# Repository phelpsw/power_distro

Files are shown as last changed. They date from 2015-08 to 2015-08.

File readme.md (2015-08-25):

## Dependencies

### Libs
 * https://github.com/phelpsw/kicad-libs
 * http://smisioto.no-ip.org/kicad_libs/library/lib_w_connectors.zip
 * http://smisioto.no-ip.org/kicad_libs/library/lib_w_transistor.zip
 * http://smisioto.no-ip.org/kicad_libs/library/lib_w_analog.zip

### Footprints
 * http://smisioto.no-ip.org/kicad_libs/modules/mod_conn_rf.zip
 * http://smisioto.no-ip.org/kicad_libs/modules/mod_smd_cap.zip
 * http://smisioto.no-ip.org/kicad_libs/modules/mod_smd_dil.zip
 * http://smisioto.no-ip.org/kicad_libs/modules/mod_smd_diode.zip
 * http://smisioto.no-ip.org/kicad_libs/modules/mod_smd_inductors.zip
 * http://smisioto.no-ip.org/kicad_libs/modules/mod_smd_leds.zip
 * http://smisioto.no-ip.org/kicad_libs/modules/mod_smd_resistors.zip
 * http://smisioto.no-ip.org/kicad_libs/modules/mod_smd_trans.zip
 * http://smisioto.no-ip.org/kicad_libs/modules/mod_conn_jst-ph.zip

### Models
 * http://smisioto.no-ip.org/kicad_libs/packages3d/3d_conn_df13.zip
 * http://smisioto.no-ip.org/kicad_libs/packages3d/3d_conn_rf.zip
 * http://smisioto.no-ip.org/kicad_libs/packages3d/3d_smd_cap.zip
 * http://smisioto.no-ip.org/kicad_libs/packages3d/3d_smd_dil.zip
 * http://smisioto.no-ip.org/kicad_libs/packages3d/3d_smd_diode.zip
 * http://smisioto.no-ip.org/kicad_libs/packages3d/3d_smd_inductors.zip
 * http://smisioto.no-ip.org/kicad_libs/packages3d/3d_smd_leds.zip
 * http://smisioto.no-ip.org/kicad_libs/packages3d/3d_smd_resistors.zip
 * http://smisioto.no-ip.org/kicad_libs/packages3d/3d_smd_trans.zip
 * http://smisioto.no-ip.org/kicad_libs/packages3d/3d_conn_jst-ph.zip

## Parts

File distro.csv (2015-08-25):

ref | value | Field1
BT1 | BATTERY | P223-ND
C1 | 100uF | 493-2226-2-ND
C2 | 100uF | 493-2226-2-ND
C3 | DNP
C4 | 10uF | 399-11082-1-ND
C5 | 0.1uF | 399-11163-1-ND
C6 | 0.033uF | 478-3769-1-ND
C7 | 0.033uF | 478-3769-1-ND
C8 | 0.033uF | 478-3769-1-ND
C9 | 0.1uF | 399-11163-1-ND
C10 | 0.1uF | 399-11163-1-ND
C11 | 0.1uF | 399-11163-1-ND
C12 | 0.022uF | 490-8308-1-ND
C13 | 0.022uF | 490-8308-1-ND
C14 | 0.022uF | 490-8308-1-ND
C15 | 0.022uF | 490-8308-1-ND
C16 | 0.022uF | 490-8308-1-ND
C17 | 0.022uF | 490-8308-1-ND
C18 | 0.1uF | 399-11163-1-ND
C19 | 0.1uF | 399-11163-1-ND
C20 | 0.1uF | 399-11163-1-ND
C21 | 0.1uF | 399-11163-1-ND
C22 | 0.1uF | 399-11163-1-ND
C23 | 0.1uF | 399-11163-1-ND
C24 | 0.1uF | 399-11163-1-ND
C25 | 0.1uF | 399-11163-1-ND
C26 | 0.1uF | 399-11163-1-ND
C27 | 0.1uF | 399-11163-1-ND
C28 | 10uF | 399-11082-1-ND
C29 | 100uF | 493-2226-2-ND
C30 | 1uF | 399-8147-1-ND
C31 | 1uF | 399-8147-1-ND
C32 | 10uF | 399-11082-1-ND
C33 | 1uF | 399-8147-1-ND
C34 | 0.1uF | 399-11163-1-ND
C35 | 0.1uF | 399-11163-1-ND
C36 | 0.022uF | 490-8308-1-ND
C37 | 1uF | 399-8147-1-ND
C38 | 0.1uF | 399-11163-1-ND
C39 | 47pF | 399-9083-1-ND
D1 | LED Green | 160-1218-1-ND
D2 | LED Green | 160-1218-1-ND
D3 | MB3045S-E3/8W | MB3045S-E3/8WGICT-ND
D4 | BI_LED | VLMV3100-GS08CT-ND
D5 | BI_LED | VLMV3100-GS08CT-ND
D6 | BI_LED | VLMV3100-GS08CT-ND
D7 | BI_LED | VLMV3100-GS08CT-ND
D8 | BI_LED | VLMV3100-GS08CT-ND
D9 | BI_LED | VLMV3100-GS08CT-ND
D10 | LED Green | 160-1218-1-ND
D11 | BI_LED | VLMV3100-GS08CT-ND
F1 | 4A 5V | F5786CT-ND
F2 | 4A 5V | F5786CT-ND
F3 | 4A 5V | F5786CT-ND
F4 | 4A 5V | F5786CT-ND
F5 | 4A 5V | F5786CT-ND
F6 | 4A 5V | F5786CT-ND
F7 | 4A 5V | F5786CT-ND
F8 | 4A 5V | F5786CT-ND
F9 | 1.85A 24V | F2871CT-ND
F10 | 1.1A 5V | F3366CT-ND
F11 | 1.1A 24V | F2868CT-ND
F12 | 2.6A 5V | F4242CT-ND
F13 | 1.1A 24V | F2868CT-ND
F14 | 1.1A 5V | F3366CT-ND
F15 | 1.1A 5V | F3366CT-ND
F16 | 1.85A 24V | F2871CT-ND
F17 | 1.1A 5V | F3366CT-ND
F18 | 1.6A 24V | F2870CT-ND
F19 | 1.6A 24V | F2870CT-ND
F20 | 1.1A 24V | F2868CT-ND
F21 | 1.6A 24V | F2870CT-ND
F22 | 1.1A 24V | F2868CT-ND
F23 | 1.6A 24V | F2870CT-ND
F24 | 1.1A 24V | F2868CT-ND
F25 | 1.1A 24V | F2868CT-ND
F26 | 1.1A 24V | F2868CT-ND
F27 | 1.1A 24V | F2868CT-ND
F28 | 1.1A 5V | F3366CT-ND
F29 | 1.1A 5V | F3366CT-ND
F30 | 1.5A 5V | F3367CT-ND
F31 | 1.1A 24V | F2868CT-ND
F32 | 1.1A 24V | F2868CT-ND
F33 | 1.85A 24V | F2871CT-ND
J1 | MEGAFIT-4SKT | WM10392-ND
J2 | DF13-4 | H3434-ND
J3 | DF13-6 | H3436-ND
J4 | DF13-5 | H3435-ND
J5 | DF13-6 | H3436-ND
J6 | SSW-116-02-S-TRA
J7 | TSW-106-02-S-TRA
J8 | SSW-108-02-S-D-RA
J9 | SSW-106-02-G-D-RA
J10 | JST-PA-4 | 455-2645-1-ND
J11 | JST-PA-2 | 455-2650-1-ND
J12 | JST-PA-2 | 455-2650-1-ND
J13 | DF13-4 | H3434-ND
J14 | JST-PA-2 | 455-2650-1-ND
J15 | JST-PA-2 | 455-2650-1-ND
J16 | JST-PA-2 | 455-2650-1-ND
J17 | JST-PA-3 | 455-2644-1-ND
J18 | JST-PA-3 | 455-2644-1-ND
J19 | JST-PA-4 | 455-2645-1-ND
J20 | JST-PA-4 | 455-2645-1-ND
J21 | JST-PA-3 | 455-2644-1-ND
J22 | JST-PA-3 | 455-2644-1-ND
J23 | JST-PA-2 | 455-2650-1-ND
J24 | JST-PA-2 | 455-2650-1-ND
J25 | JST-PA-2 | 455-2650-1-ND
J26 | JST-PA-2 | 455-2650-1-ND
J27 | DF13-6 | H3436-ND
L1 | 27nH | 490-2628-1-ND
P1 | Pad
P2 | SMA RA | A97593-ND
Q1 | IRFZ44 | IRFZ44STRRPBFCT-ND
Q2 | IRFZ44 | IRFZ44STRRPBFCT-ND
Q3 | IRFZ44 | IRFZ44STRRPBFCT-ND
Q4 | IRFZ44 | IRFZ44STRRPBFCT-ND
Q5 | IRFZ44 | IRFZ44STRRPBFCT-ND
Q6 | IRFZ44 | IRFZ44STRRPBFCT-ND
Q7 | IRFZ44 | IRFZ44STRRPBFCT-ND
Q8 | IRFZ44 | IRFZ44STRRPBFCT-ND
R1 | DNP
R2 | DNP
R3 | DNP
R4 | DNP
R5 | 2m | LVK25R002DERCT-ND
R6 | 68.1k | P68.1KDACT-ND
R7 | 10k | P10KBFCT-ND
R8 | 1.3k | P1.3KBFCT-ND
R9 | 2m | LVK25R002DERCT-ND
R10 | 75k | P75KDACT-ND
R11 | 10m | LVK25R010DERCT-ND
R12 | 100k | P100KCCT-ND
R13 | 150 | P150DACT-ND
R14 | 4.42k | P4.42KCCT-ND
R15 | 470 | P470CCT-ND
R16 | 100k | P100KCCT-ND
R17 | 510 | P510FCT-ND
R18 | 100k | P100KCCT-ND
R19 | 57.6k | P57.6KDACT-ND
R20 | 300 | P300CCT-ND
R21 | 47.5k | P47.5KDACT-ND
R22 | 66.5k | P66.5KDACT-ND
R23 | 300 | P300CCT-ND
R24 | 300 | P300CCT-ND
R25 | 47.5k | P47.5KDACT-ND
R26 | 66.5k | P66.5KDACT-ND
R27 | 300 | P300CCT-ND
R28 | 300 | P300CCT-ND
R29 | 57.6k | P57.6KDACT-ND
R30 | 57.6k | P57.6KDACT-ND
R31 | 300 | P300CCT-ND
R32 | 300 | P300CCT-ND
R33 | 4.42k | P4.42KCCT-ND
R34 | 4.42k | P4.42KCCT-ND
R35 | 4.42k | P4.42KCCT-ND
R36 | 1M | P1.00MCCT-ND
R37 | FILTER | 490-4003-1-ND
R38 | FILTER | 490-4003-1-ND
R39 | 10 | RNCP0805FTD10R0CT-ND
SW1 | M2022LL2W13 | 360-3095-ND
U1 | VHE100W | 102-2639-ND
U2 | VQE50W | 102-2627-ND
U3 | 74LS74 | 296-1079-1-ND
U4 | INA139 | 296-26061-1-ND
U5 | INA139 | 296-26061-1-ND
U6 | INA139 | 296-26061-1-ND
U7 | 74LS74 | 296-1079-1-ND
U8 | MIC5014 | 576-1233-1-ND
U9 | MIC5014 | 576-1233-1-ND
U10 | 74LS74 | 296-1079-1-ND
U11 | 74LS74 | 296-1079-1-ND
U12 | MIC5014 | 576-1233-1-ND
U13 | MIC5014 | 576-1233-1-ND
U14 | 74LS74 | 296-1079-1-ND
U15 | 74LS74 | 296-1079-1-ND
U16 | MCP601-SOT | MCP601T-I/OTCT-ND
U17 | MCP601-SOT | MCP601T-I/OTCT-ND
U18 | MCP601-SOT | MCP601T-I/OTCT-ND
U19 | MCP601-SOT | MCP601T-I/OTCT-ND
U20 | PQD6-D | 102-2886-ND
U21 | MS4525DO-DS | 223-1110-ND
U22 | 74LS74 | 296-1079-1-ND
U23 | TC1055 | TC10553.3VCT713CT-ND
U24 | NEO-M8

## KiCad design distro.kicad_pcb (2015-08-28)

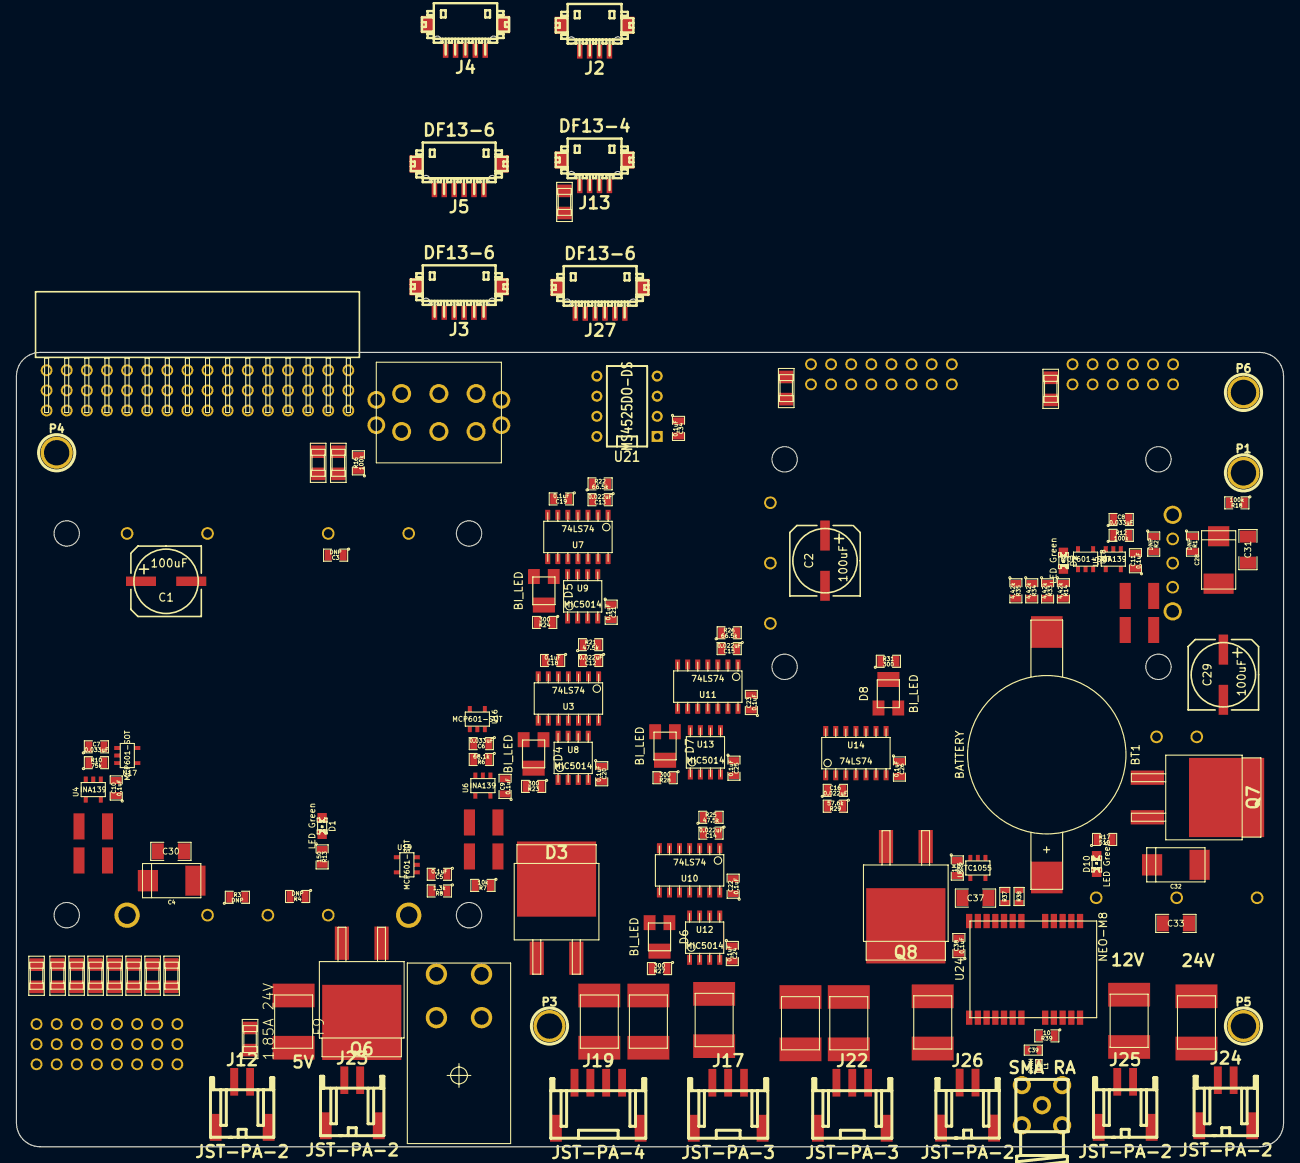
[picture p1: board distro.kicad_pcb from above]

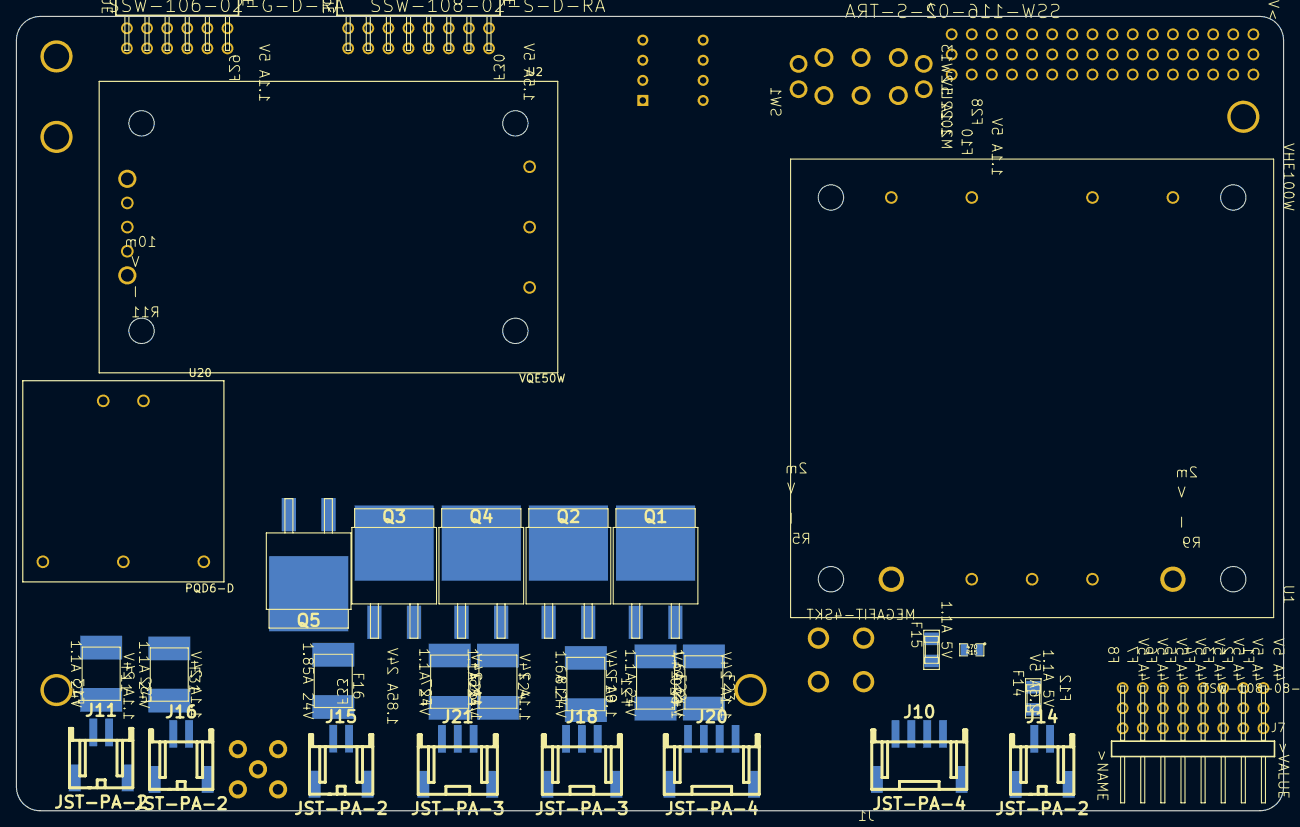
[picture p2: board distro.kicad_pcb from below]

Board: 2 copper layers, 160.0 x 100.3 mm, 178 parts (30 on the bottom side), 130 nets, no tracks yet.

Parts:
BT1: BATTERY; BR2032
C1, C2, C29: 100uF; SMDHD/VF
C3: DNP; SM0805
C4, C28, C32: 10uF; c_tant_V
C5, C9, C10, C11, C18, C19, C20, C21, C22, C23, C24, C25, C26, C34, C38: 0.1uF; SM0805
C6, C7, C8: 0.033uF; SM0805
C12, C13, C14, C15, C16: 0.022uF; SM0805
C30, C31, C33, C37: 1uF; SM1206
C39: 47pF; SM0603
D1, D2, D10: LED Green; LED-0805
D3: MB3045S-E3/8W; d2-pak
D4, D5, D6, D7, D8: BI_LED; LED_PLCC3
F1, F2, F3, F4, F5, F6, F7, F8: 4A 5V; littelfuse-1206
F9, F16, F33: 1.85A 24V; littelfuse-2920L
F10, F14, F15, F17, F28, F29: 1.1A 5V; littelfuse-1206
F11, F13, F20, F22, F24, F25, F26, F27, F31, F32: 1.1A 24V; littelfuse-2920L
F12: 2.6A 5V; littelfuse-1206
F18, F19, F21, F23: 1.6A 24V; littelfuse-2920L
F30: 1.5A 5V; littelfuse-1206
J1: MEGAFIT-4SKT; molex-MEGAFIT-4SKT-RA
J2, J13: DF13-4; df13-4p-125h
J3, J5, J27: DF13-6; df13-6p-125h
J4: DF13-5; df13-5p-125h
J6: SSW-116-02-S-TRA; con-samtec-SSW-116-02-S-T-RA
J7: TSW-108-08-G-T-RA; con-samtec-TSW-108-02-S-T-RA
J8: SSW-108-02-S-D-RA; con-samtec-SSW-108-02-S-D-RA
J9: SSW-106-02-G-D-RA; con-samtec-SSW-106-02-S-D-RA
J10, J19, J20: JST-PA-4; s4b-ph-sm4-tb
J11, J12, J14, J15, J16, J23, J24, J25, J26: JST-PA-2; s2b-ph-sm4-tb
J17, J18, J21, J22: JST-PA-3; s3b-ph-sm4-tb
L1: 27nH; inductor_smd_0402
P1, P3, P4, P5, P6: Pad; 1pin
P2: SMA RA; sma_90_r300.124.403
Q1, Q2, Q3, Q4, Q5, Q6, Q7, Q8: IRFZ44; d2-pak
R1, R2, R3, R4: DNP; SM0805
R5, R9: 2m; LVK25
R6: 68.1k; SM0805
R7: 10k; SM0805
R8: 1.3k; SM0805
R10: 75k; SM0805
R11: 10m; LVK25
R12, R16, R18: 100k; SM0805
R13: 150; SM0805
R14, R33, R34, R35: 4.42k; SM0805
R15: 470; SM0805
R17: 510; SM0805
R21, R25: 47.5k; SM0805
R22, R26: 66.5k; SM0805
R23, R24, R27, R28, R31: 300; SM0805
R29: 57.6k; SM0805
R36: 1M; SM0805
R37, R38: FILTER; SM0603
R39: 10; SM0805
SW1: M2022LL2W13; switch-M2022LL2W13
U1: VHE100W
U2: VQE50W
U3, U7, U10, U11, U14: 74LS74; so-14
U4, U5, U6: INA139; SOT23-5
U8, U9, U12, U13: MIC5014; so-8
U16, U17, U18, U19: MCP601-SOT; SOT23-5
U20: PQD6-D
U21: MS4525DO-DS; DIP-8__300
U23: TC1055; SOT23-5
U24: NEO-M8; NEO-M8N

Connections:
+3.3V: C37.1, C38.1, U23.5, U24.23
+5V: C9.1, C10.1, C11.1, C18.1, C19.1, C20.1, C21.1, C22.1, C23.1, C24.1, C25.1, C26.1, C34.1, D1.1, F1.1, F2.1, F3.1, F4.1, F5.1, F6.1, F7.1, F8.1, F9.2, F10.2, F12.2, F14.2, F15.2, F17.2, F28.2, F29.2, F30.2, Q7.1, R9.1, R36.1, U3.2, U3.4, U3.10, U3.13, U3.14, U4.5, U5.5, U6.5, U7.2, U7.4, U7.10, U7.13, U7.14, U8.1, U9.1, U10.2, U10.4, U10.10, U10.13, U10.14, U11.2, U11.4, U11.10, U11.13, U11.14, U12.1, U13.1, U14.2, U14.4, U14.10, U14.13, U14.14, U16.5, U17.5, U18.5, U19.5, U21.2, U23.1
+12V: C32.1, C33.1, D10.1, F31.2, F32.2, F33.2, U20.3
+24V: D2.1, F11.2, F13.2, F16.2, R11.1
+BATT: C1.1, C2.1, C29.1, Q1.2, Q2.2, Q3.2, Q4.2, R5.1, U1.1, U2.1, U20.2
/Identification Lights/RC_IN: U3.3, U3.12, U7.3, U7.12
/Identification Lights/STROBE: F18.2, F19.2, F21.2, F23.2, Q2.3, U9.3
/Identification Lights/SYNC: J17.3, J18.3, J19.4, J20.4
/Identification Lights/WING_LIGHT: F20.2, F22.2, Q1.3, U8.3
/Landing Lights/LANDING: F24.2, F26.2, Q4.3, U13.3
/Landing Lights/RC_IN: U10.3, U10.12, U11.3, U11.12
/Landing Lights/TAXI: F25.2, F27.2, Q3.3, U12.3
/Lidar/AUX5 (Mode): J10.3, R15.1
/Payload/Payload_Switched: D8.1, Q5.1, Q6.1, Q8.1, U14.9
/Payload/RC_IN: U14.3, U14.12
/Pixhawk/5V_CURR_MEAS: J4.2, U17.1, U17.4
/Pixhawk/24V_CURR_MEAS: J4.4, U18.1, U18.4
/Pixhawk/FMAIN1_5V: F1.2, J7.2
/Pixhawk/FMAIN2_5V: F2.2, J7.5
/Pixhawk/FMAIN3_5V: F3.2, J7.8
/Pixhawk/FMAIN4_5V: F4.2, J7.11
/Pixhawk/FMAIN5_5V: F5.2, J7.14
/Pixhawk/FMAIN6_5V: F6.2, J7.17
/Pixhawk/FMAIN7_5V: F7.2, J7.20
/Pixhawk/FMAIN8_5V: F8.2, J7.23
/Pixhawk/MAIN1: J6.30, J7.3
/Pixhawk/MAIN2: J6.27, J7.6
/Pixhawk/MAIN3: J6.24, J7.9
/Pixhawk/MAIN4: J6.21, J7.12
/Pixhawk/MAIN5: J6.18, J7.15
/Pixhawk/MAIN6: J6.15, J7.18
/Pixhawk/MAIN7: J6.12, J7.21
/Pixhawk/MAIN8: J6.9, J7.24
/Pixhawk/MEAS_CURRENT: J3.3, U16.1, U16.4
/Pixhawk/MEAS_VOLTAGE: J3.4, U19.1, U19.4
/Pixhawk/RC_SIG: J6.3, J9.1
/Power/5V_ONOFF: SW1.P2, U1.2
/Power/24V_ONOFF: SW1.P5, U2.2
GND: BT1.2, C1.2, C2.2, C3.1, C4.2, C5.2, C6.2, C7.1, C8.1, C9.2, C10.2, C11.2, C12.2, C13.2, C14.2, C15.2, C16.2, C18.2, C19.2, C20.2, C21.2, C22.2, C23.2, C24.2, C25.2, C26.2, C28.2, C30.2, C31.2, C32.2, C33.2, C34.2, C37.2, C38.2, C39.2, J1.3, J1.4, J2.4, J3.5, J3.6, J4.3, J4.5, J5.6, J6.1, J6.4, J6.7, J6.10, J6.13, J6.16, J6.19, J6.22, J6.25, J6.28, J6.31, J6.34, J6.37, J6.40, J6.43, J6.46, J7.1, J7.4, J7.7, J7.10, J7.13, J7.16, J7.19, J7.22, J8.1, J9.5, J10.4, J11.2, J12.2, J13.4, J14.2, J16.2, J17.2, J18.2, J19.3, J20.3, J21.3, J22.3, J24.2, J25.2, J27.6, P2.2, Q5.3, Q6.3, Q7.3, Q8.3, R2.1, R4.1, R6.2, R8.2, R10.1, R12.1, R13.2, R14.2, R15.2, R16.2, R17.2, R18.2, R23.2, R24.2, R27.2, R28.2, R31.2, R33.2, R34.2, R35.2, SW1.P1, SW1.P4, U1.4, U1.5, U1.6, U2.3, U2.4, U2.5, U3.7, U4.2, U5.2, U6.2, U7.7, U8.4, U9.4, U10.7, U11.7, U12.4, U13.4, U14.7, U16.2, U17.2, U18.2, U19.2, U20.5, U21.1, U23.2, U24.7, U24.10, U24.12, U24.13, U24.24
unnamed: R11.3, U5.4
unnamed: R11.4, U5.3
unnamed: D1.2, R13.1
unnamed: R9.3, U4.4
unnamed: R9.4, U4.3
unnamed: R3.2, R4.2, U1.7
unnamed: C3.2, U1.3
unnamed: R1.2, R2.2, U2.6
unnamed: R16.1, SW1.GND1, SW1.GND2, SW1.GND3, SW1.GND4
unnamed: C28.1, C31.1, R1.1, R11.2, U2.7, U2.8
unnamed: C4.1, C30.1, R3.1, R9.2, U1.8, U1.9
unnamed: R36.2, U23.4
unnamed: C29.2, Q7.2, U20.1
unnamed: D10.2, R17.1
unnamed: C8.2, R12.2, U5.1, U18.3
unnamed: C6.1, R6.1, U6.1, U16.3
unnamed: R5.4, U6.3
unnamed: R5.3, U6.4
unnamed: D3.2, R5.2, R7.1
unnamed: C5.1, R7.2, R8.1, U19.3
unnamed: C7.2, R10.2, U4.1, U17.3
unnamed: D3.1, J1.1, J1.2
unnamed: D2.2, R14.1, R33.1, R34.1, R35.1
unnamed: F28.1, J3.1, J3.2
unnamed: BT1.1, U24.22
unnamed: R37.2, U24.21
unnamed: R39.1, U24.9
unnamed: C39.1, L1.1, R39.2
unnamed: L1.2, P2.1, U24.11
unnamed: J27.3, R38.1
unnamed: R38.2, U24.20
unnamed: J27.2, R37.1
unnamed: J2.2, J13.2, U21.4
unnamed: J2.3, J13.3, U21.3
unnamed: F17.1, J13.1
unnamed: F10.1, J6.2, J6.5, J6.8, J6.11, J6.14, J6.17, J6.20, J6.23, J6.26, J6.29, J6.32, J6.35, J6.38, J6.41, J6.44, J6.47
unnamed: J8.4, J8.6
unnamed: F30.1, J8.5
unnamed: F29.1, J9.3
unnamed: F18.1, J17.1
unnamed: F21.1, J19.2
unnamed: F20.1, J19.1
unnamed: F19.1, J18.1
unnamed: D5.2, R24.1
unnamed: D5.3, U7.8
unnamed: Q1.1, U8.5
unnamed: D5.1, U7.9, U9.2
unnamed: D4.2, R23.1
unnamed: D4.1, U3.9, U8.2
unnamed: D4.3, U3.8
unnamed: F23.1, J20.2
unnamed: F22.1, J20.1
unnamed: C13.1, R22.2, U7.1
unnamed: R22.1, U7.6, U7.11
unnamed: C12.1, R21.2, U3.1
unnamed: Q2.1, U9.5
unnamed: R21.1, U3.6, U3.11
unnamed: D6.3, U10.8
unnamed: D6.2, R27.1
unnamed: D7.1, U11.9, U13.2
unnamed: D7.3, U11.8
unnamed: D7.2, R28.1
unnamed: F24.1, J21.1
unnamed: F25.1, J21.2
unnamed: D6.1, U10.9, U12.2
unnamed: Q3.1, U12.5
unnamed: F27.1, J22.2
unnamed: F26.1, J22.1
unnamed: C15.1, R26.2, U11.1
unnamed: R26.1, U11.6, U11.11
unnamed: R25.1, U10.6, U10.11
unnamed: C14.1, R25.2, U10.1
unnamed: Q4.1, U13.5
unnamed: F15.1, J10.1
unnamed: F11.1, J11.1
unnamed: F14.1, J14.1
unnamed: F12.1, J12.1
unnamed: F13.1, J24.1
unnamed: F31.1, J16.1
unnamed: F33.1, J26.1
unnamed: J26.2, Q8.2
unnamed: F32.1, J25.1
unnamed: R29.1, U14.6, U14.11
unnamed: D8.3, U14.8
unnamed: D8.2, R31.1
unnamed: J23.2, Q6.2
unnamed: C16.1, R29.2, U14.1
unnamed: F9.1, J23.1
unnamed: J15.2, Q5.2
unnamed: F16.1, J15.1
unnamed: P1.1, R18.1

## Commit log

2015-08-14 Initial cut at this board schematic using kicad.
    [battery.sch, distro.kicad_pcb, distro.sch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]
2015-08-21 Continued syncing with original design.
    [battery.sch, distro.sch, hardware.sch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]
2015-08-22 Finishing bom integration with schematic.
    [battery.sch, distro.csv, distro.sch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]
2015-08-22 Adding buffer on voltage reference output.
    [battery.sch, distro.csv, hardware.sch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]
2015-08-22 Fixing number on new buffer.
    [battery.sch, hardware.sch, id_lights.sch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]
2015-08-22 Updating design with new 12v bus.
    [battery.sch, distro.csv, distro.sch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]
2015-08-25 Adding gps receiver, updating netlist and completing component assignment.
    [battery.sch, distro.csv, distro.sch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]
2015-08-26 Updating layout and component pad configs.
    [battery.sch, distro.kicad_pcb, distro.sch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]
2015-08-28 Preliminary layout complete.
    [battery.sch, distro.kicad_pcb, distro.sch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]
